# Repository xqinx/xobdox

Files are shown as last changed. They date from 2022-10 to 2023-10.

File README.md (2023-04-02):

# xobdox
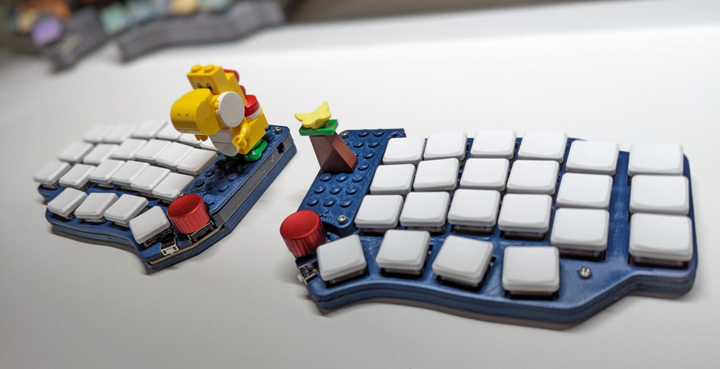
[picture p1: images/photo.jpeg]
xobdox photo

xobdox is a 40%(~ish) split wireless keyboard with a single PCB
design for both halves, featuring joystick, side button, encoder and
configurability options, powered by [ZMK](zmk.dev).

## Features
* Reversible PCB for both left and right halves
* 44/46/48 total switches/buttons
    * 44 mechanical switches, Cherry MX or Kailh low profile compatible, hot swappable
    * 2 optional side push buttons (one on each side)
    * 2 optional encoder push-down buttons (ENC2 only)
* PS2 style joystick
    * Used for mouse cursor movement emulation
    * Or as a joystick input device
* Flexible configurations
    * Choose to install either an encoder or a joystick on each side
    * Encoder can be installed at ENC1 or ENC2, joystick uses ENC2 only
    * 1u or 1.25u key caps on *some* keys

Other features are quite common in all the other DIY keyboards you can find out
there:
* Wireless (BLE) or Wired (USB) transport
* Ortho-linear (slightly modified and angled) layout
* Hot swappable switches
* Main power switch

No RGB/Glow/Backlight/Display support (yet).

## Gallery
* Some [keyboards](docs/gallery.md) I have built
* [Video](https://youtu.be/KlP1d-ixVQw) on joystick mouse movement emulation
* [Configuration](docs/configuration.md) options

## Battery life
Estimated battery life (in months)

|Battery capacity |Central(Left) side |Peripheral(Right) side |
|---|---|---|
|400mAh | 1.3 | 4.8 |
|500mAh | 1.5 | 5.7 |
|1000mAh | 3.1 | 8.5 |
|2000mAh | 5.1 | 11.3 |

## BOM
*Note* Qty is for one board/side, for a complete set of keyboard multiply Qty by
2 accordingly

|Qty|Device |Parts |
|---|---|---|
|22 |Switch Socket<sup>1</sup> |S1-S22 |
|22 |Switch<sup>1</sup> |S1-S22 |
|1  |MJTP1117 |S23 |
|24 |DKS14 |D1-D24 |
|1  |EC12E2440301<sup>2</sup> |ENC1/ENC2 |
|1  |THB001P |JOYSTICK |
|1  |1825232-1 |SW1 |
|1  |seeeduino_xiao_ble |U1 |
|1  |PKCELL LP502535<sup>3</sup> |Battery |

<sup>1</sup> Compatible with Cherry MX or Kailh low profile sockets/switches \
<sup>2</sup> Use EC12 for low profile encoder, or EC11 for standard profile encoder \
<sup>3</sup> Depends on battery configuration options, different part can be chosen

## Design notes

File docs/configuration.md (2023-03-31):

## Config Options
### Encoder
One of two locations can be used to install an encoder, though not both of them
can be used at the same time since they share the same GPIO pins.
ENC1 supports installing a knob up to 16mm diameter and ENC2 up to 25mm
respectively.
ENC2 also supports encoders with push button (e.g. EC11)
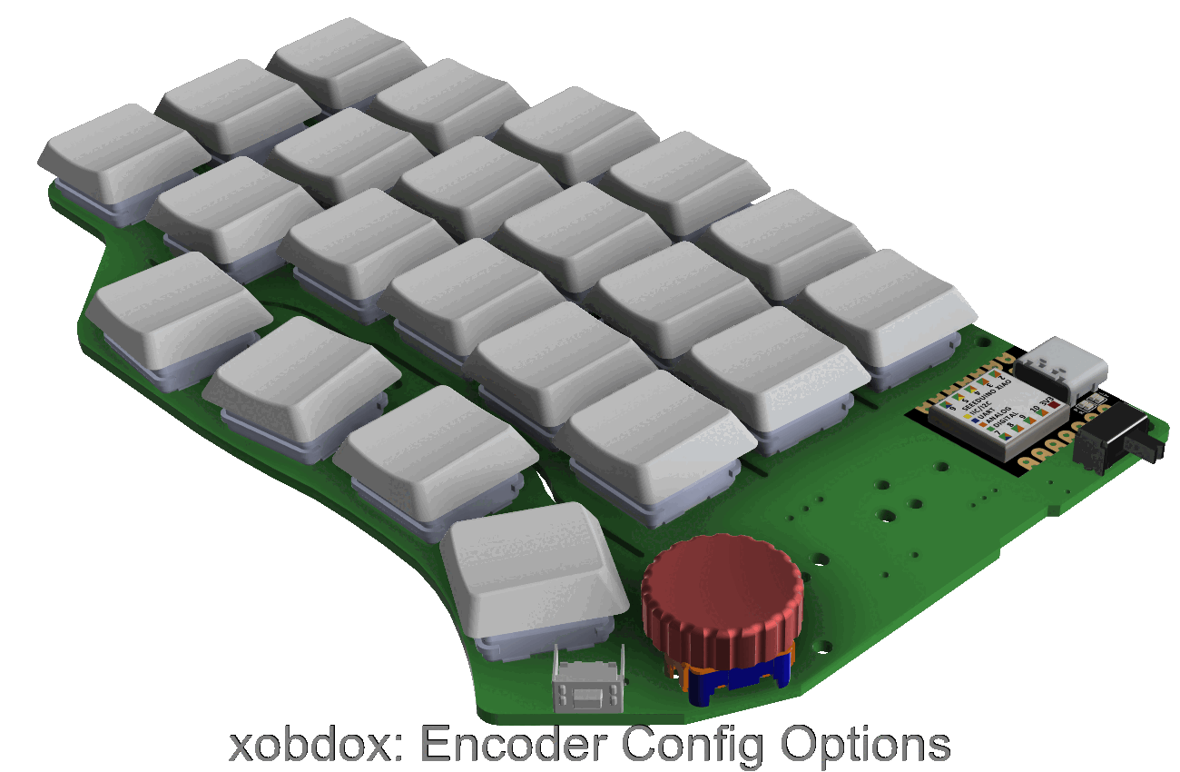
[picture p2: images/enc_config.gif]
Encoder Config

### Battery
Battery could be mounted on either side of the board.

If mounted on top, an idea size would be 25mm * 35mm * 50mm, such as a 502535 cell
[here](https://www.sparkfun.com/products/13851)

If mounted on bottom, an alternative form factor of 18350 can be used, which also
dubbed as the keyboard tilt support
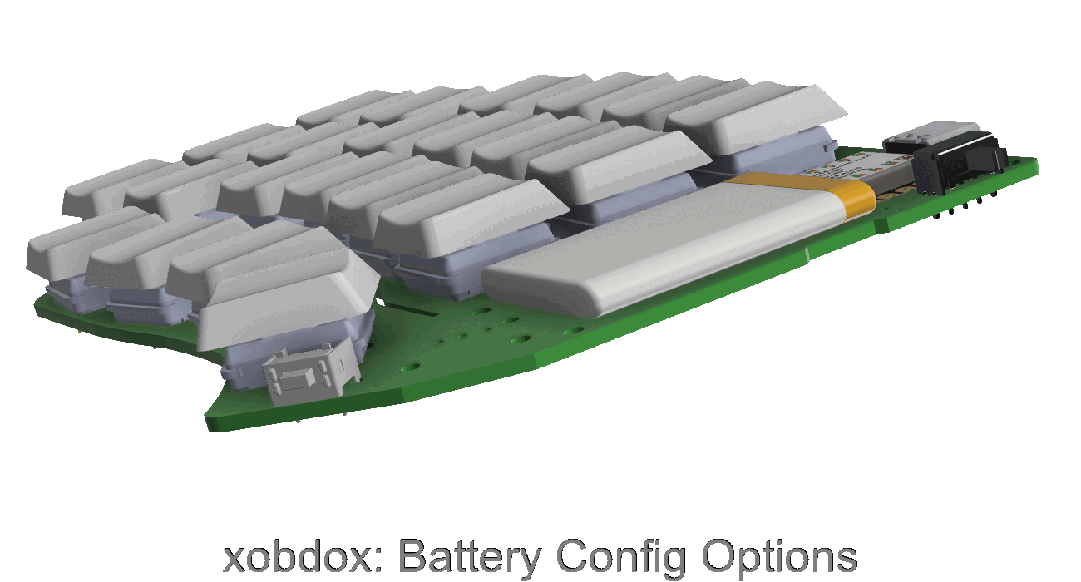
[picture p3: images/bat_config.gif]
Battery Config


### Encoder + Battery
Since there are location conflict between some of the encoder and battery
options, not all combinations of encoder and battery configs are feasible. This
gif shows all feasible ones
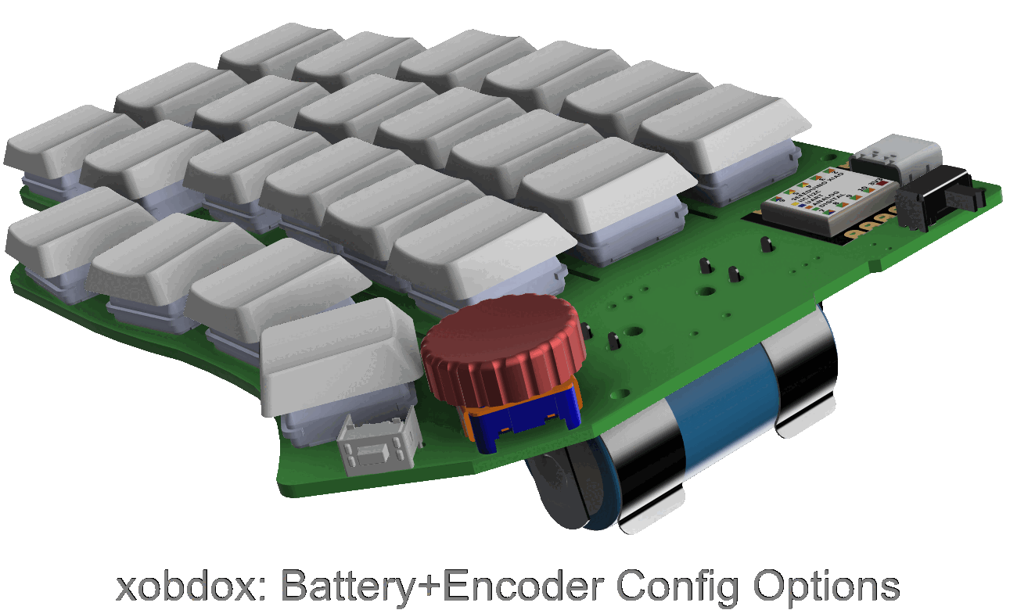
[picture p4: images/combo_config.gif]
Combo Config


### Key caps
Some key caps can use 1.25u/1.5u key caps in addition to the standard 1u size. Those
are located on the edge columns and the last row.
The following gif demonstrated some possible key caps configurations (not
exhaustive)
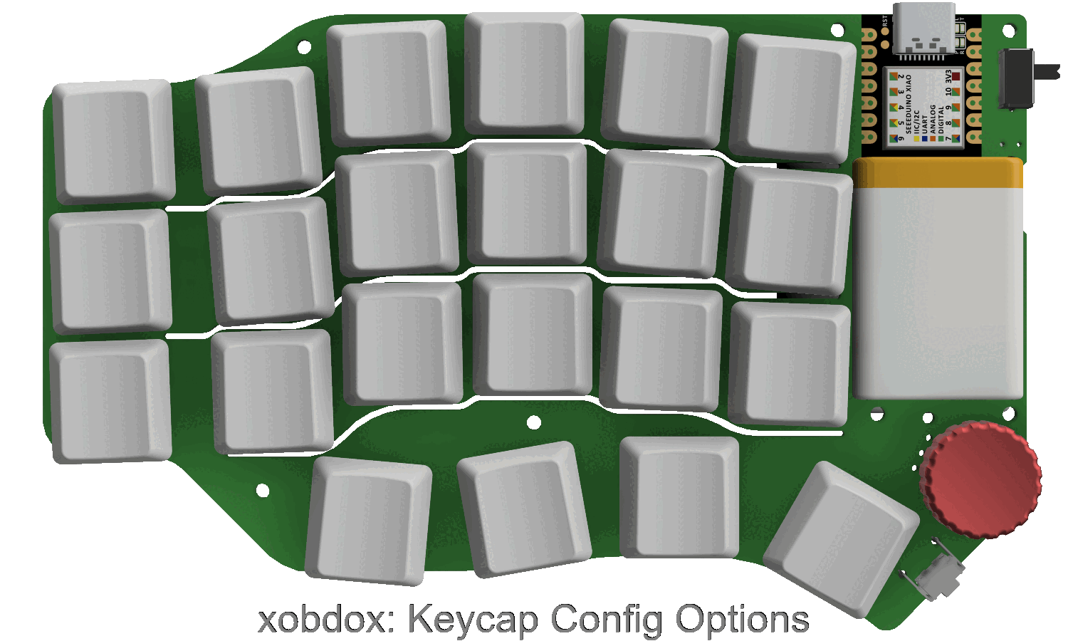
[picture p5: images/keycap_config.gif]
Keycaps Config Keycap Config


*Note1*: 1.5u option only available to the switches on the most right/left column
on row 2 and row 3.

*Note2*: not all key caps on the last row can be 1.25u, specifically, there shall
not be any consecutive 1.25u key caps.

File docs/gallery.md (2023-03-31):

## Keyboard Gallery
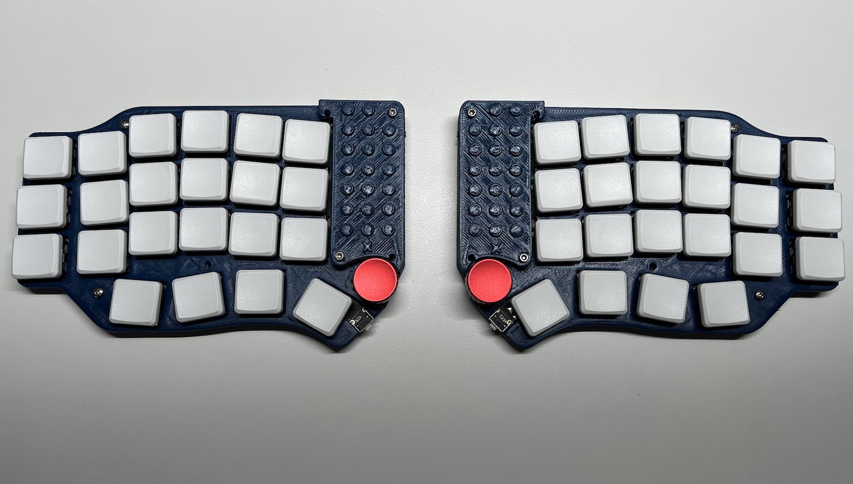
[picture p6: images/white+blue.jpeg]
White On Blue White key cap, blue case

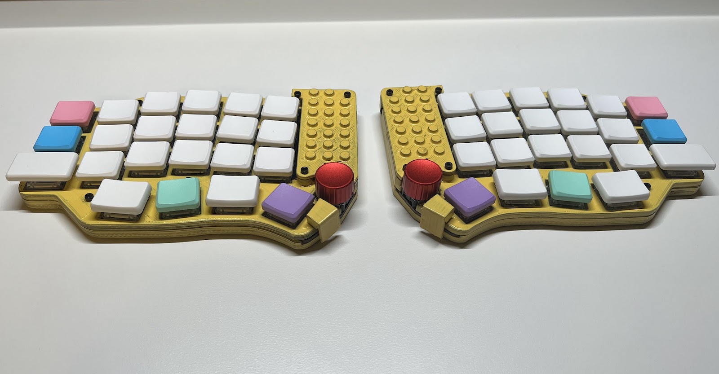
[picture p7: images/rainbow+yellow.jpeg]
Rainbow On Yellow White and color key cap, yellow case

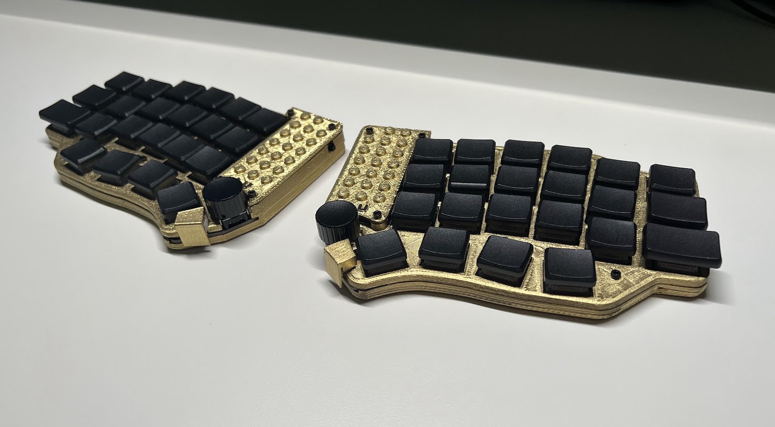
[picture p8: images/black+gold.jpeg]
Black On Gold Black key cap, gold case

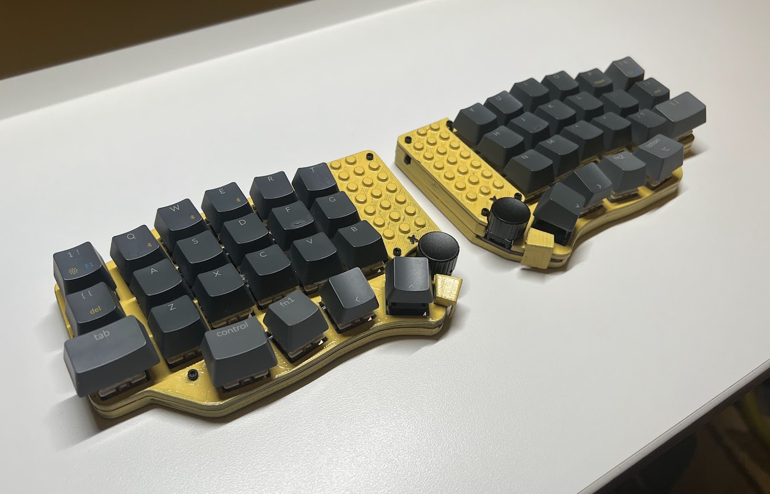
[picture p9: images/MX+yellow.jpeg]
MX On Yellow Cherry MX, yellow case


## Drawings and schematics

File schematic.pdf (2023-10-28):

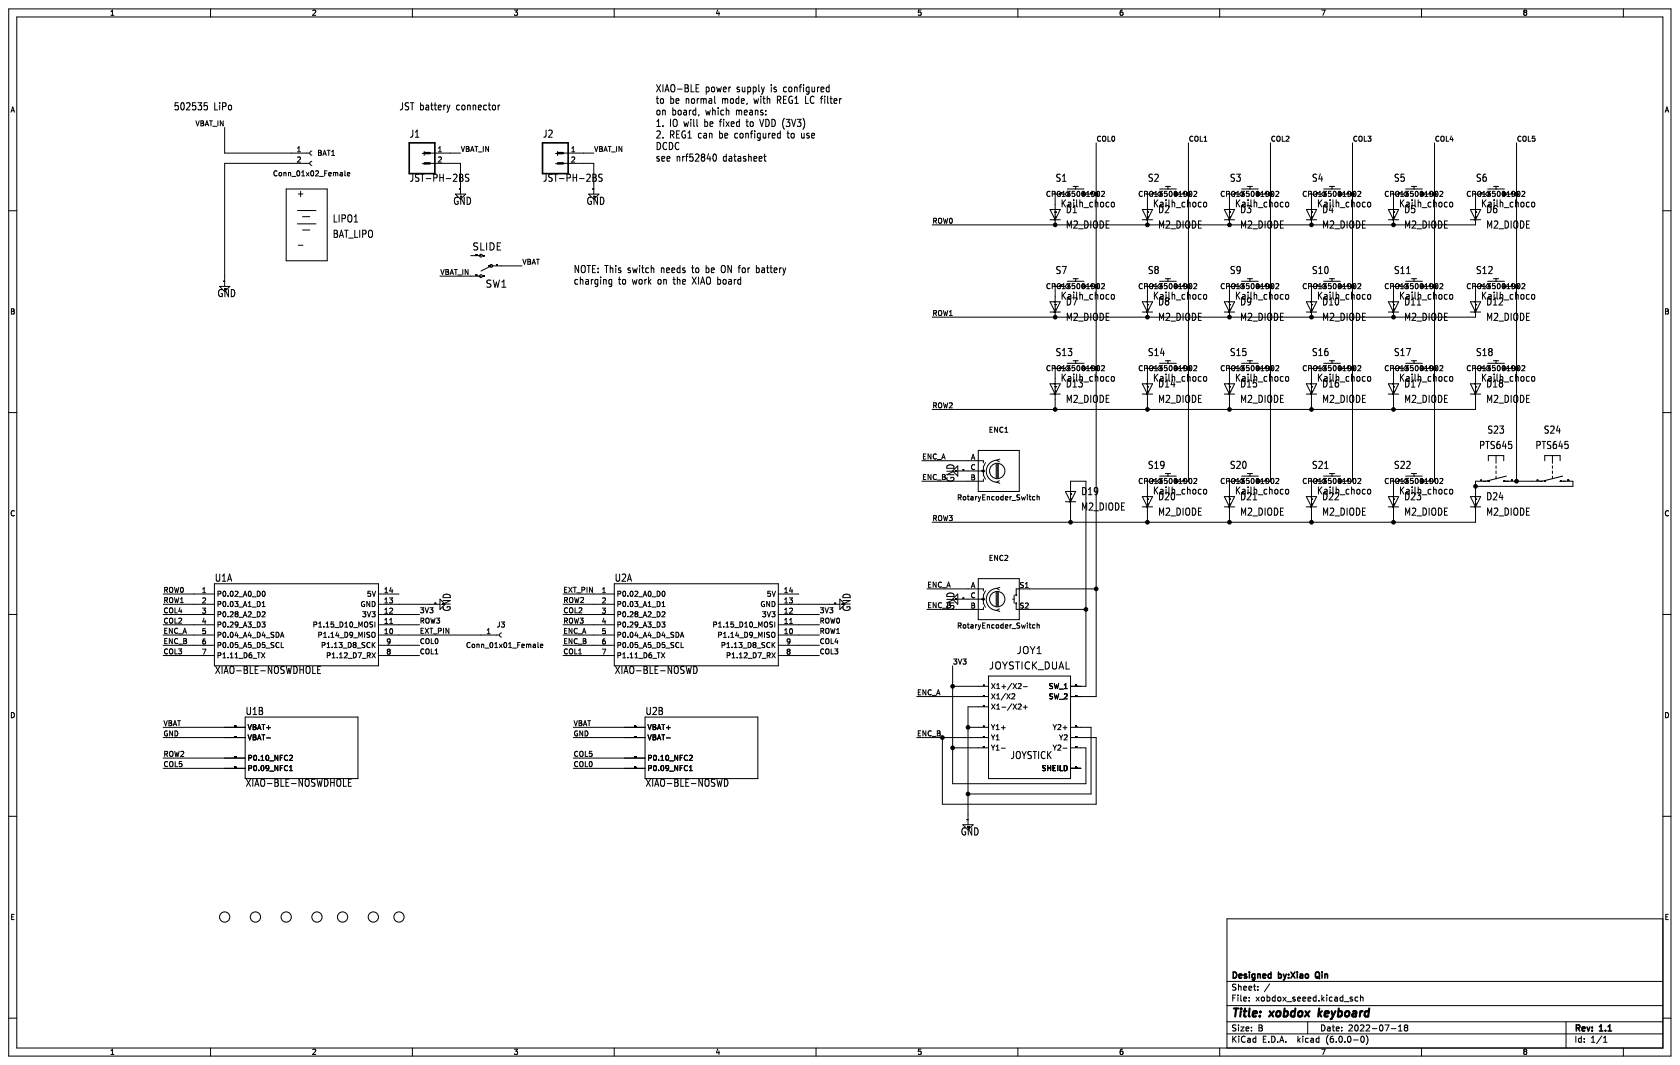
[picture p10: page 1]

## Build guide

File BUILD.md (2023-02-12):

## Customize and Build

* Check out xobdox's zmk branch: https://github.com/xqinx/zmk/tree/xobdox
* If you'd like to change any key mappings, modify the keymap file in
  `app/boards/shields/xobdox/xobdox.keymap` according to zmk's key code
  [definitions](https://zmk.dev/docs/codes)
* compile each side's firmware seperately
  you might need to setup your build environment following instructions
  [here](https://zmk.dev/docs/development/setup)
  ```shell
  cd zmk/app
  # compile for left side
  west build -p -b seeeduino_xiao_ble -- -DSHIELD=xobdox_left
  # copy artifacts out of build dir so it doesn't get overwritten by the next
  compilation for the right side
  cp build/zephyr/zmk.uf2 SOME_WHERE_YOU_CHOOSE/xobdox_left.uf2
  ```
  ```shell
  # compile for right side
  west build -p -b seeeduino_xiao_ble -- -DSHIELD=xobdox_right
  cp build/zephyr/zmk.uf2 SOME_WHERE_YOU_CHOOSE/xobdox_right.uf2
  ```

## Flash
* connect either side of the keyboard to your host machine using a USB-C cable
* double press the reset button on XIAO ble board. See
  [referece](https://wiki.seeedstudio.com/XIAO_BLE/)
* you should see a USB mass storage device show up after double pressing, that
  means the board now is in its bootloader and can be flashed over USB
* drag and drop the compiled firmware (xobdox_left.uf2 or xobdox_right.uf2
  depending on the side) to the mass storage device
* The board will flash itself and reset after it's done.
* Repeat this for the other side.

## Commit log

2022-10-26 add schematic
2023-05-22 update schematic and upload gerber files
    [xobdox_seeed-B_Cu.gbr, xobdox_seeed-B_Mask.gbr, xobdox_seeed-B_Paste.gbr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]
2023-10-04 Update schematic to support joystick
    move GPIOs around so we can have joystick support on the ADC enabled
    pins.
    This change will enable us to install a joystick or an encoder on one of
    the encoder/joystick combo locations
    [xobdox_seeed-B_Cu.gbr, xobdox_seeed-B_Mask.gbr, xobdox_seeed-B_Paste.gbr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]
2023-10-28 fix: add missing GND for ENC2
    [xobdox_seeed-B_Cu.gbr, xobdox_seeed-B_Mask.gbr, xobdox_seeed-B_Paste.gbr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]
